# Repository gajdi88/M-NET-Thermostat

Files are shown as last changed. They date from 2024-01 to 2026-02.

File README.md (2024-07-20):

# M-NET-Thermostat
Smart thermostat for Mitsubishi's M-NET communication protocol

Massive thanks to Len Shustek for figuring out the protocol. This project largely builds on his work at https://github.com/LenShustek/M-NET-Sniffer

Project bundles a simulation of the M-NET to Serial converter - including conversion to 3.3V TTL logic in preparation for a Raspberry Pi to interpret the signals.



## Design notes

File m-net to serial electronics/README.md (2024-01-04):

# M-NET to Serial adapter

Since M-NET relies on a proprietary protocol, some custom electronics are required to be able to read and write to the bus. This is to simulate the behaviour of the comms protocol in designing the electronics.

The falstad schematic can be loaded into a free circuit simluator at https://www.falstad.com/circuit/circuitjs.html

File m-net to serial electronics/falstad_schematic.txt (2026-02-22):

$ 1 0.000005 0.529449005047003 61 5 50 5e-11
c 384 336 432 336 4 2.0000000000000002e-7 1.9857070432454853 0.001 0
c 384 496 432 496 4 2.0000000000000002e-7 11.98047690953134 0.001 0
r 432 336 528 336 0 10000
r 432 496 528 496 0 10000
r 528 336 528 416 0 10000
g 528 416 528 448 0 0
w 528 336 688 336 0
w 688 336 688 416 0
w 688 448 688 496 0
w 688 496 528 496 0
r 688 544 816 544 0 10000
w 688 496 688 544 0
w 816 544 816 432 0
207 1136 448 1136 368 4 5V\slogic
x 21 349 278 471 4 14 M-NET\sis\sa\sdouble\swire\spair.\\nThis\sinput\ssimulates\s-2V\simpulses\\non\sa\s12V\srail\scoinciding\swith\\n2V\simpulses\son\sa\s0V\srail\\n\\n\s2kHz\swith\sa\s10%\sduty\scycle\sresults\sin\sthe\\nsame\spulse\slength\sas\sM-NET\spulses\\nseem\sto\sbe
x 385 232 648 303 4 14 High\spass\sfilter\sstage\sto\sremove\s12V\soffset\\nFilter\sfreq\s\q\s200nF*10kO\s\q\s2Hz\\n\\nNote:high\spass\sfilter\sis\sslow\sto\sstabilise\\nwith\sfiltering\s12V
x 684 180 806 183 4 14 Subtract\sthe\ssignals
b 864 160 1194 682 0
b 374 211 658 552 0
x 1228 195 1589 249 4 14 Monostable\smultivibrator\s(555)\\nfrom\shttps://www.falstad.com/circuit/e-555monostable.html\\n\\n1.1\s*\sR1\s*\sC1\s\q\s110us\spulses\scome\sout
w 1536 320 1536 384 0
w 1472 320 1536 320 0
g 1504 512 1504 528 0 0
c 1328 448 1280 448 4 0.000001 0.6787383271384009 0.001 0
w 1328 320 1376 320 0
r 1328 320 1328 448 0 1000
O 1568 416 1568 368 0 0
R 1328 320 1248 320 0 0 40 5 0 0 0.5
w 1376 320 1472 320 0
r 1376 384 1376 320 0 1800
g 1376 528 1376 544 0 0
c 1376 480 1376 528 4 1.0000000000000001e-7 0.9624120920580894 0.001 0
w 1376 384 1376 480 0
w 1408 448 1328 448 0
w 1408 384 1376 384 0
w 1408 384 1408 480 0
165 1408 352 1520 352 4 4.999999640201402
I 1216 448 1280 448 0 0.5 5
b 1208 163 1611 681 0
w 1136 448 1216 448 0
R 1728 336 1728 288 0 0 40 5 0 0 0.5
w 1536 416 1568 416 0
x 1636 188 1884 208 4 14 Convert\s0-5V\sline\slevels\sto\s0-3.3V\slevels\\nfor\sembedded\sserial\scomms
x 1348 347 1365 350 4 14 R1
x 1343 524 1360 527 4 14 C1
R 1808 432 1808 288 0 0 40 3.3 0 0 0.5
f 1808 432 1728 432 32 1.5 0.02
r 1728 336 1728 416 0 10000
r 1808 432 1808 512 0 10000
w 1808 512 1728 512 0
w 1728 512 1728 448 0
w 1808 512 1936 512 0
207 1936 512 1936 288 4 3.3V\slevel\slogic
z 1696 448 1696 416 2 default-zener
w 1568 416 1696 416 0
w 1728 416 1696 416 0
w 1696 448 1728 448 0
b 1625 163 2028 681 0
R 944 544 944 592 0 0 40 5 0 0 0.5
r 944 544 1008 544 0 10000
r 1008 544 1072 544 0 10000
g 1072 544 1072 560 0 0
w 1008 544 1008 464 0
w 960 432 1008 432 0
x 876 186 1007 206 4 14 Convert\s5V\sTTL\slogic\\nusing\sa\scomparator
b 676 158 846 680 0
409 1008 448 1136 448 3 0.6 -4.969873593802223 0.023100000000000002 0
g 1072 480 1072 496 0 0
R 1072 416 1072 368 0 0 40 5 0 0 0.5
409 688 432 816 432 3 0.6 -14.063922450514967 0.023100000000000002 0
R 752 400 752 352 0 0 40 12 0 0 0.5
R 752 464 752 496 0 0 40 -12 0 0 0.5
g 960 480 960 496 0 0
R 960 384 960 352 0 0 40 5 0 0 0.5
d 960 432 960 384 2 default
d 960 480 960 432 2 default
x 901 334 1012 337 4 14 Diode\sclampdown
w 816 432 832 432 0
r 896 432 960 432 0 100
w 896 432 832 432 0
x 883 461 929 481 4 14 Current\\nlimit
424 384 336 288 336 256 1 40 5 0 0 0.5 0.000052 1 2
424 384 496 256 496 256 1 40 5 0 0 0.5 0.000052 1 3
o 82 1 0 4099 20 0.0015625 0 2 82 3
o 81 1 0 4099 5 0.00078125 1 2 81 3
o 52 1 0 4099 5 0.00009765625 2 2 52 3
o 26 1 0 4098 5 0.1 3 1

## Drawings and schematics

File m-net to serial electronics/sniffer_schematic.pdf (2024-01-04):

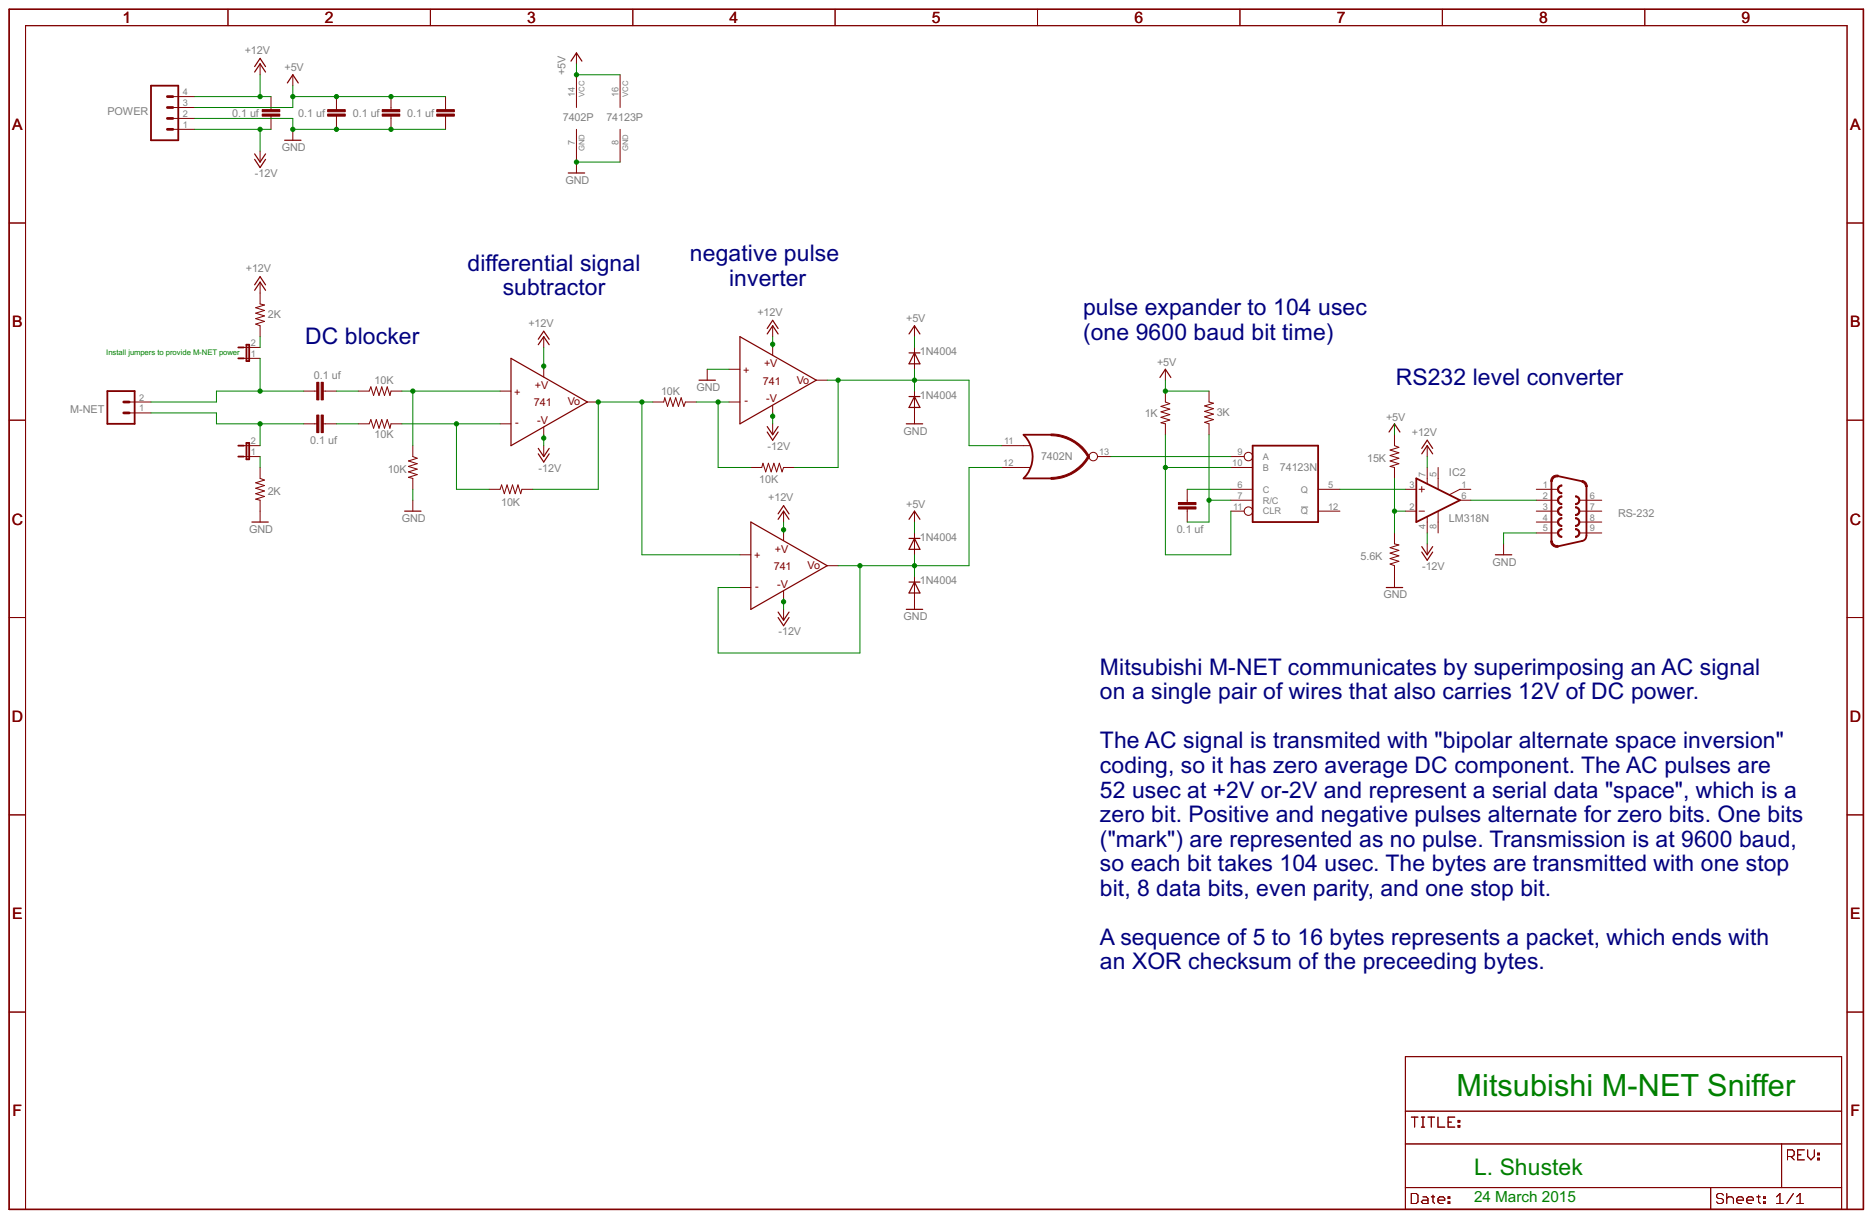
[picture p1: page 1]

pulse expander to 104 usec
(one 9600 baud bit time)

Install jumpers to provide M-NET power

Mitsubishi M-NET communicates by superimposing an AC signal
on a single pair of wires that also carries 12V of DC power. The AC signal is transmited with "bipolar alternate space inversion" coding, so it has zero average DC component. The AC pulses are

52 usec at +2V or-2V and represent a serial data "space", which is a
zero bit. Positive and negative pulses alternate for zero bits. One bits
("mark") are represented as no pulse. Transmission is at 9600 baud, so each bit takes 104 usec. The bytes are transmitted with one stop

bit, 8 data bits, even parity, and one stop bit. A sequence of 5 to 16 bytes represents a packet, which ends with

an XOR checksum of the preceeding bytes. Mitsubishi M-NET Sniffer

L. Shustek

24 March 2015

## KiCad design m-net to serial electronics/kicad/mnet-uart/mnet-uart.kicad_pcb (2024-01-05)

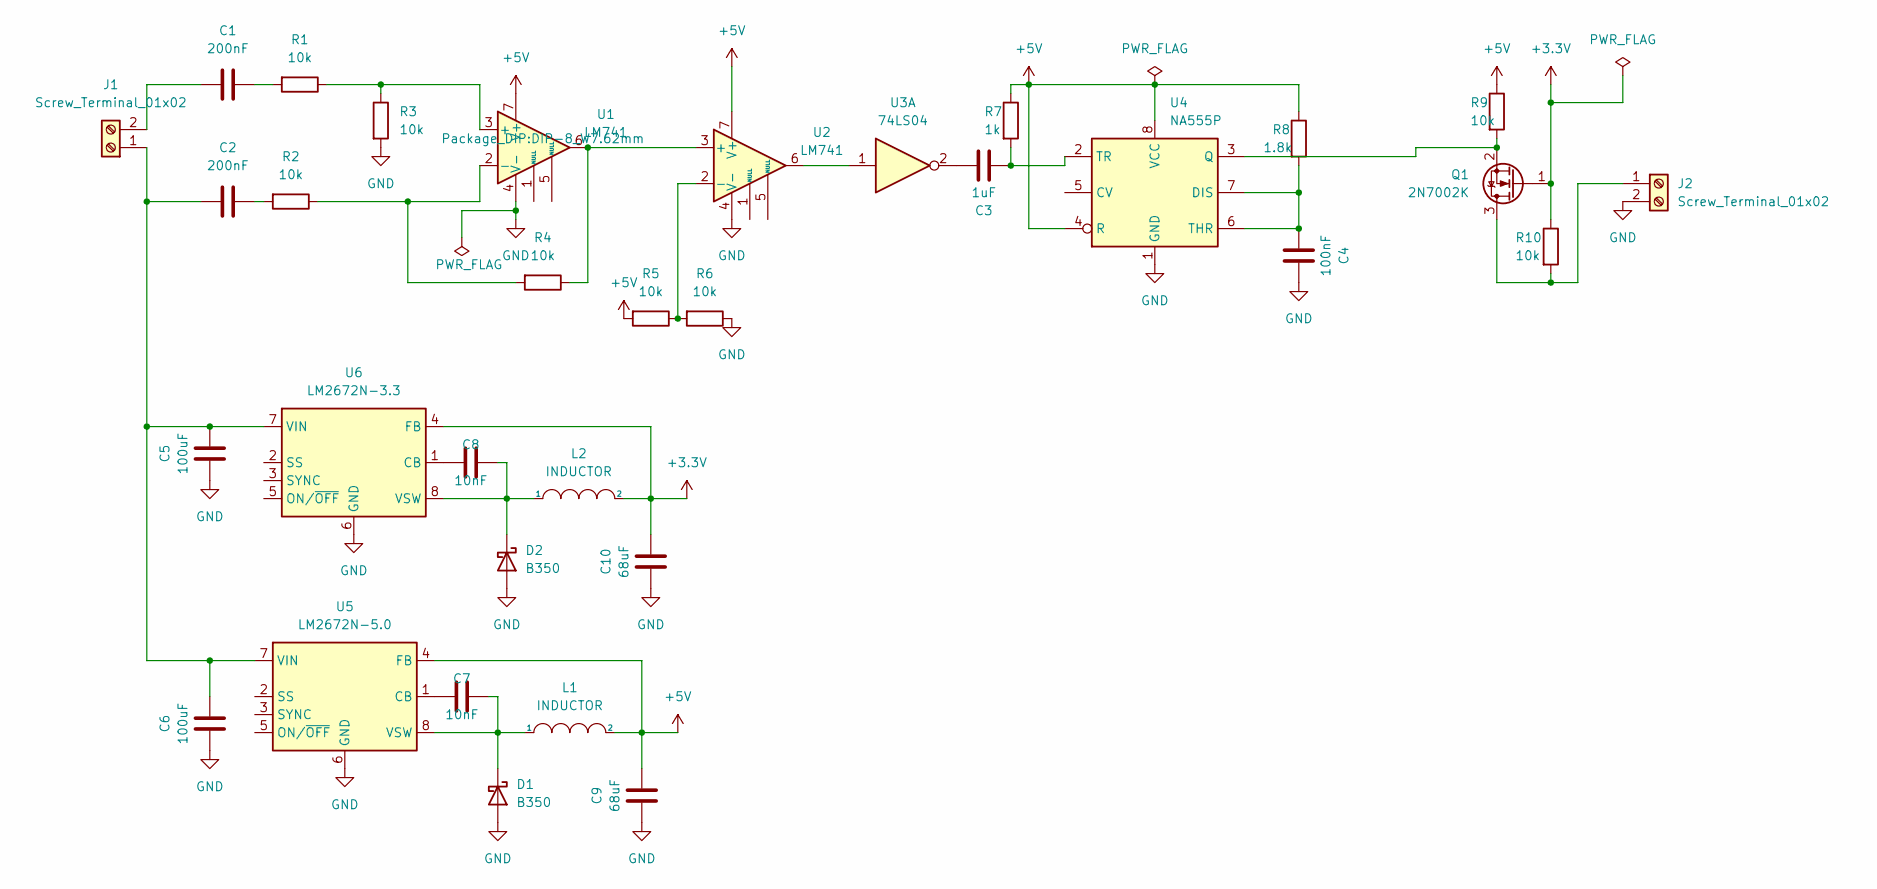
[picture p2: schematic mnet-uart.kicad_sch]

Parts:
C1, C2: 200nF; C_0805_2012Metric
C3: 1uF; C_0805_2012Metric
C4: 100nF; C_0805_2012Metric
C5, C6: 100uF; C_0805_2012Metric
C7, C8: 10nF; C_0805_2012Metric
C9, C10: 68uF; C_0805_2012Metric
D1, D2: B350; D_SMC
J1, J2: Screw_Terminal_01x02; TerminalBlock_Phoenix_MKDS-1,5-2-5.08_1x02_P5.08mm_Horizont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
L1, L2: INDUCTOR; L_Axial_L6.6mm_D2.7mm_P10.16mm_Horizontal_Vishay_IM-2
Q1: 2N7002K; SOT-23
R1, R2, R3, R4, R5, R6, R9, R10: 10k; R_0805_2012Metric
R7: 1k; R_0805_2012Metric
R8: 1.8k; R_0805_2012Metric
U1, U2: LM741; DIP-8_W7.62mm
U3: 74LS04; DIP-14_W7.62mm
U4: NA555P; DIP-8_W7.62mm
U5: LM2672N-5.0; DIP-8_W7.62mm
U6: LM2672N-3.3; DIP-8_W7.62mm

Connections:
+3.3V: C10.1, L2.2, Q1.1 (G), R10.1, U6.4 (FB)
+5V: C9.1, L1.2, R5.2, R7.1, R8.1, R9.1, U1.7 (V+), U2.7 (V+), U4.4 (R), U4.8 (VCC), U5.4 (FB)
GND: C4.1, C5.2, C6.2, C9.2, C10.2, D1.2 (A), D2.2 (A), J2.2, R3.2, R6.1, U1.4 (V-), U2.4 (V-), U4.1 (GND), U5.6 (GND), U6.6 (GND)
unnamed: C1.1, J1.2
unnamed: C1.2, R1.2
unnamed: C2.1, R2.2
unnamed: C2.2, C5.1, C6.1, J1.1, U5.7 (VIN), U6.7 (VIN)
unnamed: C3.1, U3.2
unnamed: C3.2, R7.2, U4.2 (TR)
unnamed: C4.2, R8.2, U4.6 (THR), U4.7 (DIS)
unnamed: C7.1, U5.1 (CB)
unnamed: C7.2, D1.1 (K), L1.1, U5.8 (VSW)
unnamed: C8.1, U6.1 (CB)
unnamed: C8.2, D2.1 (K), L2.1, U6.8 (VSW)
unnamed: J2.1, Q1.3 (D), R10.2
unnamed: Q1.2 (S), R9.2, U4.3 (Q)
unnamed: R1.1, R3.1, U1.3 (+)
unnamed: R2.1, R4.2, U1.2 (-)
unnamed: R4.1, U1.6, U2.3 (+)
unnamed: R5.1, R6.2, U2.2 (-)
unnamed: U2.6, U3.1

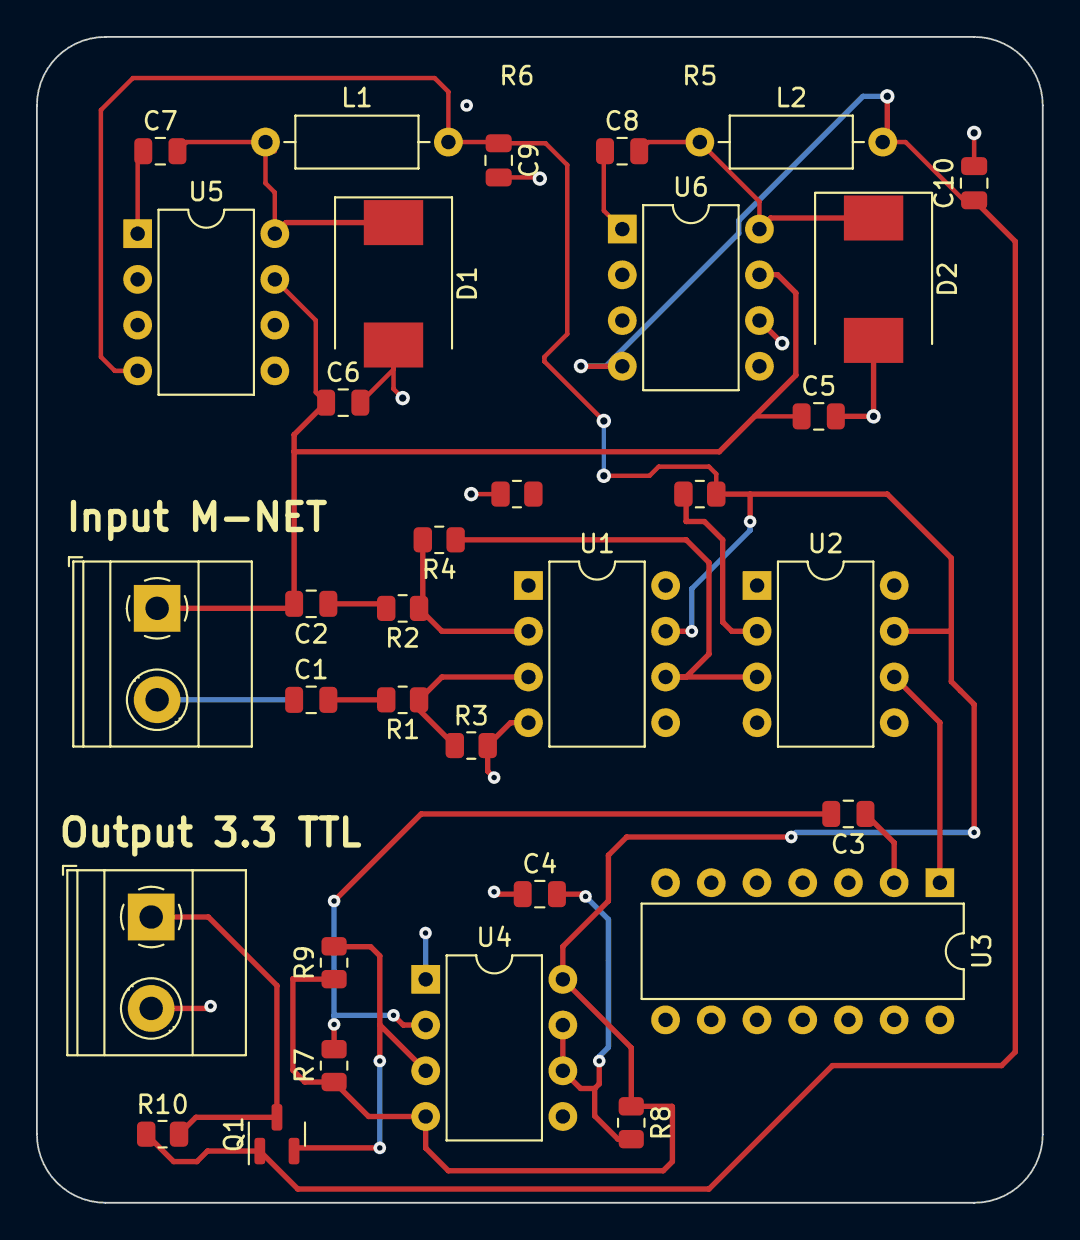
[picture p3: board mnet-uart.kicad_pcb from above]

Board: 2 copper layers, 55.9 x 64.8 mm, 33 parts (0 on the bottom side), 21 nets.

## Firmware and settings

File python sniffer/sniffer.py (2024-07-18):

import serial
import time
import datetime

VERSION = "1.2"

# Configuration constants
MNET_COM_PORT = '/dev/ttyS0'  # Adjust as per your setup
BAUD_RATE = 9600
TIMEOUT = 10  # Timeout in seconds
MAX_DATA = 20
COOLMASTER_ADDR = 0xfb
ACK = 0x06
NAK = 0x21

# Global variables
packet = bytearray(MAX_DATA + 6)
raw_datacount = 0
crc = 0
prev_from_addr = 0
prev_to_addr = 0
filter_unit = -1  # Unit to filter for; -1 is none
mnet_active = False
skipping_packet = False
filtering_packet = False
logfile = None

def delta_time(start_time):
    delta = datetime.datetime.now() - start_time
    return int(delta.total_seconds() * 1000)

def open_serial(port, baudrate):
    return serial.Serial(port, baudrate, timeout=TIMEOUT)

def close_serial(ser):
    ser.close()

def output(fmt, *args):
    message = fmt % args
    print(message, end="")
    logfile.write(message)

def newline():
    global raw_datacount, crc, skipping_packet
    output("\n")
    raw_datacount = 0
    crc = 0

def showtime(delta):
    output("%5d.%03d  " % (delta // 1000, delta % 1000))

def print_addr(addr):
    if addr == COOLMASTER_ADDR:
        output("CM")
    else:
        output("%02X" % addr)

def showtemp(pos):
    deg_c = packet[pos] * 10 + (packet[pos + 1] >> 4) + (packet[pos + 1] & 0xf) / 10.0
    output(" %.1f deg C, %.1f deg F" % (deg_c, deg_c * 9 / 5 + 32))

def showfanspeed(pos):
    parm = packet[pos]
    output(" %s" % ("low" if parm == 4 else "medium" if parm == 5 else "high" if parm == 6 else "auto" if parm == 0x0b else "???"))

def poweron():
    parm = packet[2]
    output("turn %s" % ("on" if parm == 1 else "off" if parm == 0 else "??"))

def poweron_ack():
    output(" ok")

def getstatus():
    output("get status")

def getstatus_ack():
    parm = packet[2]
    output("%s" % (" stopped" if parm == 0 else " running" if parm == 1 else "???"))

def getmode():
    output("get mode")

def getmode_ack():
    parm = packet[2]
    output("%s" % (" heat" if parm == 7 else " cool" if parm == 8 else " fan only" if parm == 0x0d else "???"))

def getsetpoint():
    output("get setpoint temp")

def getsetpoint_ack():
    showtemp(2)

def getfanspeed():
    output("get fan speed")

def getfanspeed_ack():
    showfanspeed(2)

def setfanspeed():
    output("set fan speed")
    showfanspeed(2)

def setfanspeed_ack():
    output(" ok")

def getcurrenttemp():
    output("get current temp")

def getcurrenttemp_ack():
    showtemp(3)

def setmode():
    parm = packet[2]
    output("set mode %s" % ("heat" if parm == 7 else "cool" if parm == 8 else "auto" if parm == 32 else "???"))

def setmode_ack():
    output(" ok")

def settemp():
    output("set temp ")
    showtemp(2)

def settemp_ack():
    output(" ok")

pkt_formats = [
    ([0xff, 0xff, 0xff], [5, 0x0d, 0x01], poweron),
    ([0xff, 0xff, 0xff, 0xff], [3, 0x0d, 0x81, 0x00], poweron_ack),
    ([0xff, 0xff, 0xff], [3, 0x0d, 0x02], setmode),
    ([0xff, 0xff, 0xff, 0xff], [3, 0x0d, 0x82, 0x00], setmode_ack),
    ([0xff, 0xff, 0xff], [5, 0x05, 0x01], settemp),
    ([0xff, 0xff, 0xff, 0xff], [3, 0x05, 0x81, 0x00], settemp_ack),
    ([0xff, 0xff, 0xff], [3, 0x0d, 0x0e], setfanspeed),
    ([0xff, 0xff, 0xff, 0xff], [3, 0x0d, 0x8e, 0x00], setfanspeed_ack),
    ([0xff, 0xff, 0xff], [2, 0x2d, 0x01], getstatus),
    ([0xff, 0xff, 0xff], [5, 0x2d, 0x81], getstatus_ack),
    ([0xff, 0xff, 0xff], [2, 0x2d, 0x02], getmode),
    ([0xff, 0xff, 0xff], [3, 0x2d, 0x82], getmode_ack),
    ([0xff, 0xff, 0xff], [2, 0x25, 0x01], getsetpoint),
    ([0xff, 0xff, 0xff], [5, 0x25, 0x81], getsetpoint_ack),
    ([0xff, 0xff, 0xff], [2, 0x2d, 0x0e], getfanspeed),
    ([0xff, 0xff, 0xff], [3, 0x2d, 0x8e], getfanspeed_ack),
    ([0xff, 0xff, 0xff, 0xff], [3, 0x35, 0x03, 0x22], getcurrenttemp),
    ([0xff, 0xff, 0xff, 0xff], [5, 0x35, 0x83, 0x22], getcurrenttemp_ack),
]

def decode_packet():
    global raw_datacount, crc, skipping_packet, prev_from_addr, prev_to_addr
    delta = 0
    if raw_datacount >= 5:
        packet_len = packet[4]
        if raw_datacount == 6 + packet_len:
            if crc != 0:
                output("*** bad CRC *** ")
                for i in range(raw_datacount):
                    output("%02X ", packet[i])
                output("\n")
                skipping_packet = True
                crc = 0
        if raw_datacount == 7 + packet_len:
            if not filtering_packet:
                showtime(delta)
                for i in range(raw_datacount):
                    output("%02X ", packet[i])
                match_packet()
                newline()
            filtering_packet = False
            crc = 0
            raw_datacount = 0

def match_packet():
    global prev_from_addr, prev_to_addr
    packet_len = packet[4]
    for fmt in pkt_formats:
        match = True
        for i in range(len(fmt[0])):
            if (packet[4 + i] & fmt[0][i]) != fmt[1][i]:
                match = False
                break
        if match:
            fmt[2]()
            break
    else:
        output("???")

def main():
    global raw_datacount, crc, skipping_packet, mnet_active, filtering_packet, logfile
    start_time = datetime.datetime.now()

    with open("log.txt", "a") as logfile:
        ser = open_serial(MNET_COM_PORT, BAUD_RATE)
        mnet_active = True
        try:
            while mnet_active:
                c = ser.read(1)
                if len(c) == 1:
                    crc += c[0]
                    if raw_datacount < MAX_DATA:
                        packet[raw_datacount] = c[0]
                        raw_datacount += 1
                    else:
                        if not skipping_packet:
                            output("***too much data ")
                            skipping_packet = True
                    if raw_datacount == 4 and not skipping_packet:
                        if filter_unit == -1 or packet[1] == filter_unit or packet[2] == filter_unit:
                            delta = delta_time(start_time)
                        else:
                            filtering_packet = True
                    decode_packet()
                else:
                    if not skipping_packet:
                        newline()
                        delta = delta_time(start_time)
                        showtime(delta)
                        newline()
                        skipping_packet = False
        except KeyboardInterrupt:
            pass
        finally:
            close_serial(ser)

if __name__ == "__main__":
    main()

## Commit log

2024-01-04 First version of simulating the M-NET circuit to serial converter
2024-01-04 added comments on schematic
2024-01-04 Added comments on high pass filter
2024-01-04 Converted to 3.3V logic so that RPI and ESP8266 can read the UART serial comms
2024-01-04 5V supply op amps
2024-01-04 switched to real IC741 opamps
2024-01-04 kicad schematics
    [mnet-uart.kicad_pcb, mnet-uart.kicad_sch]
2024-01-04 kicad schematics draft1
    [mnet-uart.kicad_sch]
2024-01-04 Schematics and layout updates
    [mnet-uart.kicad_pcb, mnet-uart.kicad_sch]
2024-01-05 added power supply
    [mnet-uart.kicad_pcb, mnet-uart.kicad_sch]
2024-07-21 Added diode clampdown to 0v to 5v
    note: too high current
2024-07-21 Added current limiting resistor
2026-02-22 Shustek's schematic
2026-02-22 data inputs for circuit sim
